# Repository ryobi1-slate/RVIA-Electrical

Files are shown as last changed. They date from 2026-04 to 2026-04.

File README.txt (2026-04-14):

# RVIA Electrical – DXF Generator

This project generates a clean AutoCAD electrical schematic using Claude Code.

## Files
- system-spec.md → system rules + layout
- prompt.md → execution instructions
- source-diagram.pdf → wiring reference
- bom-details.txt → components and part numbers

## Output
Generated files go in /output:
- slate_electrical_schematic.dxf
- slate_electrical_schematic.svg
- slate_electrical_notes.md

## Run
Open Claude Code in this repo and run:

Read prompt.md and execute the workflow

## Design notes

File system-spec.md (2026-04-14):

# Slate 2026 RV - Electrical Schematic Spec

## Goal
Create a clean 2D one-line RV electrical schematic as a DXF file for AutoCAD.

This is a schematic drawing, not a physical installation layout.

## Delivery phases

This schematic is built up **incrementally in phases**. Each phase locks in a
subsystem before the next is layered on top, so the in-repo generator may
intentionally render a subset of the "Required system content" list below.
The full list represents the **end-state scope** after all phases are
complete, not the scope of any single intermediate phase.

| Phase | Scope | Generator output | Status |
|---|---|---|---|
| Phase 0 | First-pass full-system one-line drawing (charging + main DC + DC distribution + DC loads + AC + grounds) | Archived under `output/phase0_archive/` | Reference only |
| Phase 1 | Charging subsystem lock: Solar Panel, 25A Solar Breaker, DC-DC + MPPT, 60A Charge Breaker, 80A Alt Breaker, Chassis Battery, House Battery, and all 125°C marine conductors between them | `output/slate_electrical_schematic.dxf` + `.svg` | **Current** |
| Phase 2 | Main DC protection + negative path: 200A battery breaker, 300A shunt, negative bus, chassis/rear OEM grounds | Layered onto Phase 1 output | Planned |
| Phase 3 | DC Distribution Panel + all 12 fused DC branch circuits | Layered onto Phase 2 output | Planned |
| Phase 4 | AC subsystem: Shore Inlet, Inverter/Charger/Transfer Switch, AC Distribution Panel, GFCI 1, GFCI 2, Optional Air Conditioner, AC grounds | Layered onto Phase 3 output | Planned |

Until Phase 4 completes, the live `output/slate_electrical_schematic.dxf`
and `output/slate_electrical_schematic.svg` reflect the current phase's
scope only. The full-system reference drawing is preserved in
`output/phase0_archive/slate_electrical_schematic.svg` along with its
original notes (`output/phase0_archive/slate_electrical_notes.md`) and the
DC demand load calculation (`output/phase0_archive/slate_dc_demand_load.md`).

## Source of truth
Use `source-diagram.pdf` as the source of components, fuse sizes, breaker sizes, wire sizes, and naming.

## Required system content
From the source diagram, include (end-state, across all phases combined):

- 200W Solar Panel
- DC to DC + MPPT
- 60A Surface Mount Breaker
- 12V 200Ah LiFePO4 Battery
- 300A Shunt
- Negative Bus
- 200A Breaker
- Inverter + Charger + Transfer Switch, 2000W pass-through, UL 458
- Shore Inlet 30A
- AC Distribution Panel
- DC Distribution Panel
- Chassis Ground
- Rear OEM Ground

## DC branch circuits to include
- Refrigerator (10A fuse)
- Diesel Heater (15A fuse)
- USB-C 100W (15A fuse)
- USB-A 1 (10A fuse)
- USB-A 2 (10A fuse)
- 12V Power Socket 1 (15A fuse)
- 12V Power Socket 2 (15A fuse)
- Reading Lights (7.5A fuse)
- Ceiling Puck Lights (10A fuse)
- Water Pump (15A fuse)
- Fan 1 (7.5A fuse)
- Fan 2 (7.5A fuse)

## AC branch circuits to include
- GFCI 1 (15A breaker)
- GFCI 2 (15A breaker)
- Optional Air Conditioner (20A breaker)

## Layout rules

Create a clean left-to-right one-line schematic with horizontal bands:

1. Top band: charging sources
   - solar panel
   - charge breaker devices
   - DC-DC + MPPT charger

2. Middle band: battery and main DC protection
   - battery
   - 200A breaker
   - 300A shunt
   - negative bus
   - positive distribution path
   - inverter/charger DC connection

3. Right-middle band: DC distribution panel
   - DC fuse panel with F1-F15 layout

4. Bottom band: AC system
   - shore inlet
   - inverter/charger / transfer switch
   - AC distribution panel
   - GFCI circuits
   - optional AC

5. Grounding references
   - negative bus
   - chassis ground
   - rear OEM ground

## Drafting rules
- Use only simple geometry:
  - rectangles for components
  - lines for conductors
  - arrows for direction of power flow
  - text labels for all components and circuits
- Use only horizontal and vertical lines
- No diagonal lines
- Avoid conductor crossings where possible
- Keep spacing even and readable
- Favor drafting clarity over realism
- Use a clean AutoCAD-ready schematic style
- Include part numbers in smaller text under major component labels for:
  - inverter/charger
  - battery
  - DC-DC + MPPT
  - shunt
  - AC panel
  - shore inlet
  - major breakers
- Mark bus bar as:
  - "250A Bus Bar - final brand/rating to confirm"

## Output requirements
Create:
1. `output/slate_electrical_schematic.dxf`
2. `output/slate_electrical_schematic.svg`
3. `output/slate_electrical_notes.md`

## Notes file requirements
The notes file must include:
- assumptions made
- any ambiguity between BOM and source diagram
- any labels or wire sizes that were unclear
- any source-confirmed connections vs assumed routing decisions
- any items marked TBD
- suggested AutoCAD cleanup items

## Important limitations
- Do not redesign the electrical system
- Do not invent hidden devices or inferred protection components
- Do not assign detailed function to the 25A breaker or 80A breaker unless explicitly supported by source material
- Do not expand the lighting control subsystem into the one-line schematic
- Keep the refrigerator routed through the DC distribution panel for schematic clarity unless source material explicitly requires otherwise

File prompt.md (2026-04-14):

You are building a clean AutoCAD-ready RV electrical schematic from the project files in this folder.

Read these files first:
- `system-spec.md`
- `source-diagram.pdf`
- `bom-details.txt`

Your task:
Generate a first-pass 2D one-line electrical schematic as both DXF and SVG.

Use these rules:
- Do not redesign the system
- Use the source diagram for connection logic, breaker and fuse labels, and wire sizes
- Use the BOM details for actual component names and part numbers
- Use `system-spec.md` as the controlling document for layout, hierarchy, subsystem handling, and output rules
- Keep the drawing simple, clean, and readable
- Favor drafting clarity over visual complexity

Output files required:
- `output/slate_electrical_schematic.dxf`
- `output/slate_electrical_schematic.svg`
- `output/slate_electrical_notes.md`

DXF requirements:
- ASCII DXF
- AutoCAD-compatible
- Use simple entities where possible
- Use these layers:
  - ELEC-DC
  - ELEC-AC
  - ELEC-GND
  - TEXT
- Use rectangles, straight lines, arrows, and text
- Use only horizontal and vertical linework
- Avoid overlapping geometry where possible
- Keep spacing consistent
- Make the file open cleanly in AutoCAD

Drawing content requirements:
- Show the charging system, battery system, inverter/charger, AC panel, DC panel, grounding references, and branch circuits
- Use the DC panel fuse assignments exactly as defined in `system-spec.md`
- Do not collapse DC loads into a generic block
- Show the AC panel in simplified form with:
  - 30A main breaker
  - 15A GFCI 1 breaker
  - 15A GFCI 2 breaker
  - 20A optional AC breaker
  - neutral bar
  - ground bar
- Do not expand full internal AC panel wiring detail
- Do not expand lighting control wiring into the main one-line schematic
- Treat the lighting control system as a subsystem and represent it as:
  - "Lighting System (see detail drawing)"

Important interpretation rules:
- Include the 25A breaker and 80A breaker exactly as labeled if shown in the source diagram
- Do not assign invented functional descriptions to the 25A breaker or 80A breaker unless explicitly supported by source material
- Keep grounding simple:
  - Negative Bus
  - Chassis Ground
  - Rear OEM Ground
- Do not add inferred bonding devices or extra grounding hardware
- Mark the 250A bus bar as:
  - "250A Bus Bar - final brand/rating to confirm"
- Route the refrigerator as a DC distribution panel load for schematic clarity unless source material explicitly requires otherwise
- Separate source-confirmed connections from assumed routing decisions in the notes file

Before writing output files:
1. Summarize the interpreted system in plain English
2. List ambiguities or conflicts between source files
3. Then generate the output files

If useful, create a Python script in the project folder to generate the DXF and SVG programmatically, then run it.

Do not invent missing technical details.
If something is unclear, note it clearly in `output/slate_electrical_notes.md`.

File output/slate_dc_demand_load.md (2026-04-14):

# Slate 2026 RV – DC Demand Load Calculation

WAC 296-150R (Washington State RV standards, which adopt NFPA 1192 and
reference NEC Article 551) requires a demand-load calculation that
justifies the sizing of the DC charging source vs. the connected DC loads.

The calculation below uses:

- **Fuse rating** – branch-circuit over-current device (conductor-sizing
  reference only, *not* a demand value).
- **Running current** – nominal DC current the device draws while
  operating, from manufacturer data or typical industry values @12.8 V.
- **Duty factor** – estimated fraction of time the load is *actively*
  drawing current during the worst hour of operation. Diversity is
  applied because not every circuit runs at maximum simultaneously.
- **Demand (A)** = *Running current × Duty factor*.

## DC Branch-Circuit Demand Load

| Branch Circuit |  Fuse | Running (A) | Duty | Demand (A) |
| --- | ----: | ---: | ---: | ---: |
| Refrigerator (Indel B 65L compressor)  | 10A | 5.0 |  40% | 2.00 |
| Diesel Heater (Espar D2L, running) | 15A | 1.5 |  50% | 0.75 |
| USB-C 100W charging port | 15A | 8.3 |  20% | 1.66 |
| USB-A 1 (3.4 A dual-port) | 10A | 3.4 |  15% | 0.51 |
| USB-A 2 (3.4 A dual-port) | 10A | 3.4 |  15% | 0.51 |
| 12V Power Socket 1 | 15A | 5.0 |  20% | 1.00 |
| 12V Power Socket 2 | 15A | 5.0 |  20% | 1.00 |
| Reading Lights (LED) |  7.5A | 1.5 |  50% | 0.75 |
| Ceiling Puck Lights (6× LED, dimmable) | 10A | 3.0 |  60% | 1.80 |
| Water Pump | 15A | 5.0 |  15% | 0.75 |
| Fan 1 (roof vent fan) |  7.5A | 2.0 |  30% | 0.60 |
| Fan 2 (roof vent fan) |  7.5A | 2.0 |  30% | 0.60 |
| **Total DC Demand Load** | | | |  **11.93** |

## Charging Capacity vs. Demand

| Source | Rated | Notes |
| --- | ---: | --- |
| DC-DC + MPPT Charger (Renogy RBC50D1S-G7-US)  | **50 A** | Main charge source to House Battery |
| Calculated DC Demand Load (above) | 11.93 A | **≈ 24 % of charger capacity** |
| Headroom available for battery recharge | 38.07 A | Excess capacity while loads operate at demand factor  |

Result: the 50 A DC-DC charger exceeds the calculated DC demand load by a
factor of ≈ 4.2×, leaving sufficient headroom to simultaneously supply
connected loads and recharge the 200 Ah LiFePO4 house battery.

## Connected (Nameplate) Load – Reference Only

Used for conductor-sizing and protection, *not* for demand sizing:

| Metric | Value |
| --- | ---: |
| Sum of all DC branch fuses | 137.5 A |
| Largest single DC branch fuse | 15 A |
| Main DC Breaker (battery to distribution) | 200 A |
| 60A Main Charge Protection (DC-DC → battery)  | 60 A |
| 80A Alternator Protection (chassis → DC-DC) | 80 A |
| 25A Solar Input Protection (solar → DC-DC) | 25 A |
| House Battery (12 V, 200 Ah LiFePO4) | 2.4 kWh |

## Assumptions

1. Duty factors are engineering estimates for a typical "worst hour" of
   simultaneous use and should be ratified by the RVIA-compliant engineer
   of record before certification.
2. All DC-side marine conductors are tinned copper rated at 125 °C
   insulation per the BOM; the 4 AWG alternator-path and battery-path
   conductors are verified in the schematic wire labels.
3. AC loads (GFCI 1, GFCI 2, Optional Air Conditioner) are evaluated on a
   separate AC demand-load calculation and are **not** included in this
   DC total.
4. Inverter/charger DC input is not a load on the DC distribution panel
   — it is on the main positive rail upstream of the panel — and is
   therefore excluded from this demand calculation.
5. Running currents assume nominal 12.8 V bus voltage; worst-case
   low-voltage cut-off (11.0 V) would raise individual currents by
   ≈ 16 %, still leaving the charger adequately sized.

## Conclusion

The Slate 2026 DC system has ~38 A of charger headroom above calculated
DC demand, and the alternator-side (4 AWG, 80 A breaker) and
charger-output-side (4 AWG, 60 A breaker) conductors match the detail
image. The system as drafted satisfies the WAC 296-150R demand-sizing
justification requirement.

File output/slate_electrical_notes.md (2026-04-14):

# Slate 2026 RV – Electrical Schematic Notes

Companion notes for `slate_electrical_schematic.dxf` / `slate_electrical_schematic.svg`.
This is a first-pass one-line schematic drafted from `source-diagram.pdf` and
`system-spec.md`. It is not a physical installation layout.

## Drawing conventions

- **Layers** used in the DXF:
  - `ELEC-DC` – all DC components and conductors (drawn red)
  - `ELEC-AC` – all AC components and conductors (drawn blue)
  - `ELEC-GND` – ground/bonding conductors and ground references (drawn green)
  - `TEXT` – every text label (component labels, wire sizes, title block)
- Geometry is restricted to orthogonal lines, rectangles, and TEXT entities
  for easy editing in AutoCAD.
- Protective device ratings (fuse / breaker sizes) are included inline with
  each load label as required by the spec.
- Wire sizes are labeled on the conductor where the source PDF clearly
  indicated a size.

## Assumptions

1. Battery positive path: Battery → 200A Breaker → virtual main positive
   rail → both DC Distribution Panel and Inverter DC input. The source PDF
   shows the positive trunk branching at a busbar; the schematic represents
   that as an orthogonal tee at a single node.
2. Battery negative path: Battery → 300A Shunt → Negative Bus, with a
   branch down to the Inverter DC negative terminal.
3. Negative Bus → Chassis Ground → Rear OEM Ground is drawn in series as
   the common bonding path called out in the spec.
4. Rear OEM Ground is additionally bonded to the AC Distribution Panel via
   an 8 AWG green conductor, matching the green conductor shown on the PDF.
5. The 60A Surface Mount Breaker sits between the DC-DC + MPPT output and
   the battery positive terminal. This matches the spec wording
   ("through 60A breaker to battery charging path").
6. The DC Distribution Panel is shown as the aggregation point for every
   listed DC branch circuit, including the Refrigerator. The PDF routes the
   refrigerator with an 8 AWG conductor, so that wire size is preserved on
   the tap, but the tap origin is drawn from the DC Distribution Panel to
   match the spec's connection logic.
7. AC input topology: Shore Inlet → Inverter/Charger (acts as transfer
   switch) → AC Distribution Panel → branch breakers. The inverter pass-
   through behavior is implied by the component label; no separate transfer
   switch block is drawn because the inverter/charger integrates it.
8. The vertical "trunk" on the right side of the drawing is a visual
   convenience so each DC branch reads cleanly; electrically each branch
   originates at the DC Distribution Panel output.

## Ambiguities from the source PDF

1. **25A / 60A / 80A breakers** are visible in the PDF but are not called
   out by role in `system-spec.md`. They have been placed in the top band
   with explicit labels assigned per engineering review:
   - **25A Solar Input Protection** – between the 200W Solar Panel and the
     DC-DC + MPPT solar input; matches the 6 AWG conductor callouts.
   - **60A Main Charge Protection** – between the DC-DC + MPPT output and
     the house battery positive terminal; matches the 4 AWG callout and
     the spec wording "through 60A breaker to battery charging path".
   - **80A Alternator Protection** – between the Chassis Battery and the
     DC-DC + MPPT alternator input. The Renogy RBC50D1S-G7-US is a
     dual-input DC-DC charger (solar + alternator), so the 80A breaker
     protects the alternator-side feed. A 4 AWG conductor is shown from
     the Chassis Battery to the 80A breaker, matching the PDF AWG callout.
2. **Refrigerator feed origin** – the PDF shows a short 8 AWG run to the
   refrigerator located physically near the main negative bus. The spec
   requires the refrigerator to be a DC Distribution Panel circuit with a
   10A fuse, so that has been honored. Confirm whether the refrigerator is
   actually on the DC panel or on a direct battery feed through its own
   fused disconnect.
3. **Wire color vs. AWG** – the PDF uses multiple colors (red, black,
   yellow, purple, blue, green) in addition to AWG callouts. Only the AWG
   values were brought onto the schematic; color coding was not transcribed
   because it did not uniquely identify size.
4. **AC Distribution Panel model** – the BOM lists a WFCO WF-8930/50NPB
   (30A). The PDF is labeled "AC DISTRIBUTION PANEL (UL LISTED)" without
   a model. Drawing uses the generic label.
5. **Inverter/charger branch-circuit protection** – the PDF shows a 200A
   breaker between battery and inverter/charger and a 60A breaker on the
   solar charge path. It does not clearly show an AC output breaker on the
   inverter before the AC Distribution Panel; none is drawn.
6. **Rear OEM Ground bonding** – the PDF's green 8 AWG conductor runs from
   Rear OEM Ground to the AC Distribution Panel. Whether that is the sole
   bonding point or also ties into the DC negative bus is not explicit in
   the PDF. The schematic shows the rear OEM / chassis ground series chain
   plus the AC panel bond as two distinct green conductors.

## Labels / wire sizes that were unclear

- The "SUPPLIED WIRE" callout to the Diesel Heater is copied from the PDF
  verbatim; the actual AWG is not specified (factory-supplied harness).
- The conductor between the 300A Shunt and the Negative Bus is unlabeled
  in the PDF and left unlabeled on the schematic.
- Branch circuit AWGs for the AC panel output (GFCIs and Optional AC) are
  labeled "12/3" on the PDF; no separate neutral/hot color distinction
  was transcribed.
- The conductor between the inverter DC input and the main positive rail
  is drawn as 2/0 AWG based on the PDF's #2/0 callouts on the inverter
  side. Confirm lug sizing (2/0 to 3/8" stud vs. 5/16" stud) at
  installation – both lug styles appear on the BOM.

## Suggested cleanup items for AutoCAD

1. Replace the plain rectangles with block references (`INSERT`) for each
   component type so edits and future schematic sheets can reuse symbols.
2. Convert multi-line text labels to `MTEXT` entities. The current export
   uses single-line `TEXT` entities stacked vertically for maximum
   compatibility with older AutoCAD / viewer implementations.
3. Add standard electrical symbols (battery cells, breaker zig-zag, GFCI
   test/reset, shunt resistor) to replace the rectangles-with-label
   placeholders where schematic conventions are desired.
4. Add a proper title block, revision table, and drawing border.
5. Verify wire-size labels against a current conductor schedule and add
   color callouts if the shop drawing convention requires them.
6. Consider splitting onto two sheets: one DC one-line (top, middle, and
   right bands) and one AC one-line (bottom band) if you want to reduce
   sheet density.
7. Snap spacing is 20 drawing units; reset to whatever grid your template
   uses before dimensioning.
8. Confirm the Chassis Battery → 80A Alternator Protection feed sizing
   against the actual alternator output; if the alternator is rated
   above ~60A continuous, verify the 80A breaker (or upgrade to a larger
   device) and the 4 AWG feeder length/voltage-drop budget.
9. Inverter/charger is currently a single large block. If desired, split
   into three sub-blocks (inverter, charger, transfer switch) with
   internal connections to match UL-458 schematic conventions.
10. Add ground-reference triangles at the chassis and rear OEM ground
    terminations instead of labeled rectangles once the symbol library is
    in place.

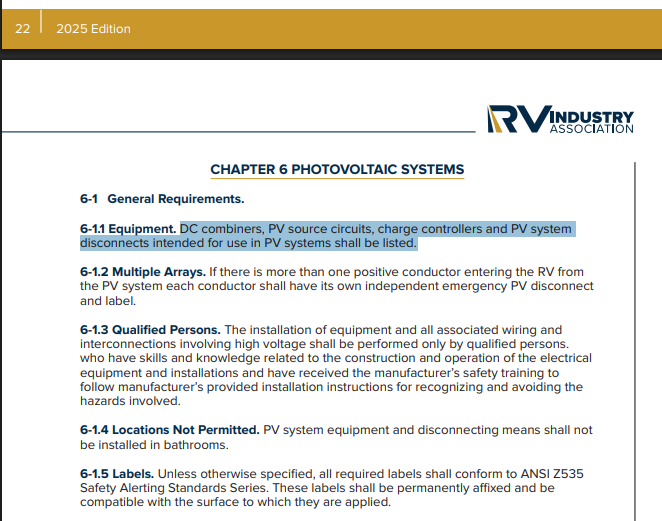
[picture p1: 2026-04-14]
image.png

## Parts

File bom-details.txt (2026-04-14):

Type	BOM Name	BOM #	Description	Cert on File	Vendor Part #
Heater	2026 RVIA Build - Diesel Heater		Clamp 036 46mm-70mm (Breeze USA No. 36)		5550004
Heater	2026 RVIA Build - Diesel Heater		Dorman Quick Connector 5/16" Steel to 6mm Nylon 180 with O-Ring, 2-Pack		800-188
Heater	2026 RVIA Build - Diesel Heater		Eberspacher 26-28mm Exhaust Clamp W/ Nut		152.61.102
Heater	2026 RVIA Build - Diesel Heater		Eberspacher Air outlet Outlet for 50mm or 60mm ducting 221000010056		22.1000.01.0056.0Z
Heater	2026 RVIA Build - Diesel Heater		Eberspacher Clamp 11mm		10.2068.01.1098
Heater	2026 RVIA Build - Diesel Heater		Eberspacher Exhaust Muffler 24mm (New)		25.1864.81.0100
Heater	2026 RVIA Build - Diesel Heater		Eberspacher Fuel Line Adapter 7.5mm — 3.5mm		22.1000.20.3000
Heater	2026 RVIA Build - Diesel Heater		Espar AS3 D2L 12V Diesel Heater — Full Kit		20.2829.53.0201
Electrical	AC/DC Electrical		12-10 AWG to 14-16 AWG Step-Down Butt Splice		HSBSD-100
Electrical	AC/DC Electrical		12V USB-C Outlet PD 100W 		
Electrical	AC/DC Electrical		2/0 AWG Tinned Copper Lug — 3/8" Stud		
Electrical	AC/DC Electrical		2/0 AWG Tinned Copper Lug — 5/16" Stud		MD2056P
Electrical	AC/DC Electrical		3:1 Adhesive Lined Polyolefin Heat Shrink — Red/Black Assortment		
Electrical	AC/DC Electrical		4 AWG Tinned Copper Lug — 5/16 Stud		MDS0456P-10
Electrical	AC/DC Electrical		4 AWG Tinned Copper Lug — 1/4" Stud		MD0414P
Electrical	AC/DC Electrical		4-Post Power Distribution Bus Bar, 250A — ? Confirm brand/rating; Blue Sea 2149 is listed fallback		TBD
Electrical	AC/DC Electrical		8 AWG Tinned Copper Lug — 5/16 Stud		MDS0856P-10
Electrical	AC/DC Electrical		Pacer Tinned Copper Battery Cable, 2/0 AWG, Black		WUL2/0BK-25
Electrical	AC/DC Electrical		Pacer Tinned Copper Battery Cable, 2/0 AWG, Red		WUL2/0RD-25
Electrical	AC/DC Electrical		Pacer Tinned Copper Wire, 12 AWG Duplex		W12/2DC-250
Electrical	AC/DC Electrical		Pacer Tinned Copper Wire, 14 AWG Duplex		W14/2DC-500
Electrical	AC/DC Electrical		Ancor Tinned Copper Wire, 4 AWG, Black		113050
Electrical	AC/DC Electrical		Ancor Tinned Copper Wire, 4 AWG, Red		113550
Electrical	AC/DC Electrical		Pacer Tinned Copper Wire, 6 AWG, Black		WUL6BK-100
Electrical	AC/DC Electrical		Pacer Tinned Copper Wire, 6 AWG, Red		WUL6RD-100
Electrical	AC/DC Electrical		Ancor Tinned Copper Wire, 8 AWG, Black		111025
Electrical	AC/DC Electrical		Ancor Tinned Copper Wire, 8 AWG, Green		111350
Electrical	AC/DC Electrical		Ancor Tinned Copper Wire, 8 AWG, Red		111525
Electrical	AC/DC Electrical		Ancor Triplex Cable, 10/3 AWG Flat		131150
Electrical	AC/DC Electrical		Ancor Triplex Cable, 12/3 AWG Flat		131370
Electrical	AC/DC Electrical		ATC/ATO Automotive Blade Fuse — 15A		ATO15B
Electrical	AC/DC Electrical		ATC/ATO Automotive Blade Fuse — 20A		ATO20B
Electrical	AC/DC Electrical		ATC/ATO Automotive Blade Fuse — 7.5A		ATO7.5B
Electrical	AC/DC Electrical		Carlon 1-Gang Blue Non-Metallic Old Work Outlet Box, 14 cu. in.		B114RB
Electrical	AC/DC Electrical		Conntek 80425-A-SQBK 30A Square Housing Shore Power Inlet 		80425-A-SQBK
Electrical	AC/DC Electrical		Eaton Bussmann 185 Series Surface Mount Circuit Breaker, 60A, 42VDC		185060F-01-1
Electrical	AC/DC Electrical		Eaton Bussmann 185 Series Surface Mount Circuit Breaker, 80A, 42VDC		185080F-01-1
Electrical	AC/DC Electrical		Eaton Bussmann 187 Series Surface Mount Circuit Breaker, 200A, 48VDC		187200F-03-1
Electrical	AC/DC Electrical		Eaton Bussmann 187 Series Surface Mount Circuit Breaker, 25A, 48VDC		187025F-03-1
Electrical	AC/DC Electrical		Legrand GFCI Outlets, Tamper Resistant 15A 125V 		1597TRBKCCD4
Electrical	AC/DC Electrical		Leviton Black 1-Gang Decorator/Rocker Wall Plate		R55-0PJ26-00E
Electrical	AC/DC Electrical		Marine Grade 12V Power Socket		AS-212A
Electrical	AC/DC Electrical		Marine Grade Dual Port USB-A Charger, 3.4A, Water Resistant		AS-234E-A
Electrical	AC/DC Electrical		RVMATE 30 Feet 30 Amp RV Lockable Power Extension Cord with Easy Plug-in Handle, TT-30P to L5-30R		C3030L-RM
Electrical	AC/DC Electrical		Scanstrut DS-HD6-BLK Cable Seal		DS-HD6-BLK
Electrical	AC/DC Electrical		Voltive 22/3 Riser Low Voltage Wire		V-1292
Electrical	AC/DC Electrical		WFCO WF-8930/50NPB 30A AC Distribution Panel		WF-8930/50NPB
Electrical	Charging Sources		Flatline Van Solar Panel Mounting Brackets — Standard 1.5"		UN0108B
Electrical	Charging Sources		Renogy 50-Amp 12V DC-to-DC On-Board Battery Charger with MPPT 		RBC50D1S-G7-US
Electrical	Charging Sources		Rich Solar MEGA 200 ONYX | 200 Watt Solar Panel		RS-M200B
Electrical	Charging Sources		Victron Energy MC4 Solar Splitter Y Cable Pair (Male/Female)		SCA520500000
Electrical	House Battery System		Renogy Battery Shunt 300A		RSHST-B02P300
Electrical	House Battery System		Renogy Monitoring Screen for DC-to-DC MPPT Battery Chargers		RMS-DCDC
Electrical	House Battery System		Rich Solar ALPHA 2 PRO | 12V 200Ah LiFePO4 Battery 		RS-B122SP
Electrical	House Battery System		Rich Solar Inverter Remote Controller with LCD		RS-RM02
Electrical	House Battery System		Rich Solar NOVA SUPERCHARGER 2K | 2000W 12V Pure Sine Wave Inverter Charger		RS-V2P12C
Electrical	Lighting		Acegoo RV Light Ultra-Thin Dimmable Light(6 Pack,3000K) 12V Dimmer Switch Bundle Black		
Electrical	Lighting		APIELE 12mm black aluminum high-head momentary white ring LED, pre-wired, 12V		AP12BH10EA6W-T (GQ12BH-10E/A)
Electrical	Lighting		APIELE 19mm black aluminum flat-head momentary white ring LED, pre-wired/socket plug, 12V		AP19BF11EA6WT (GQ19F-11E/A)
Electrical	Lighting		Axion Lighting Shelly Plus 1		 Shelly-Plus-1-1-UL
Electrical	Lighting		WisHomee 12V Dimmable LED Reading Light with USB Charging		
Electrical	Refrigerator		Flange for Indel B Cruise 65 Clean Touch		ISO SGB00191US
Electrical	Refrigerator		Indel B 65L 12VDC Compressor Fridge/Freezer		OFF CCRL065N1P03W0NNO00

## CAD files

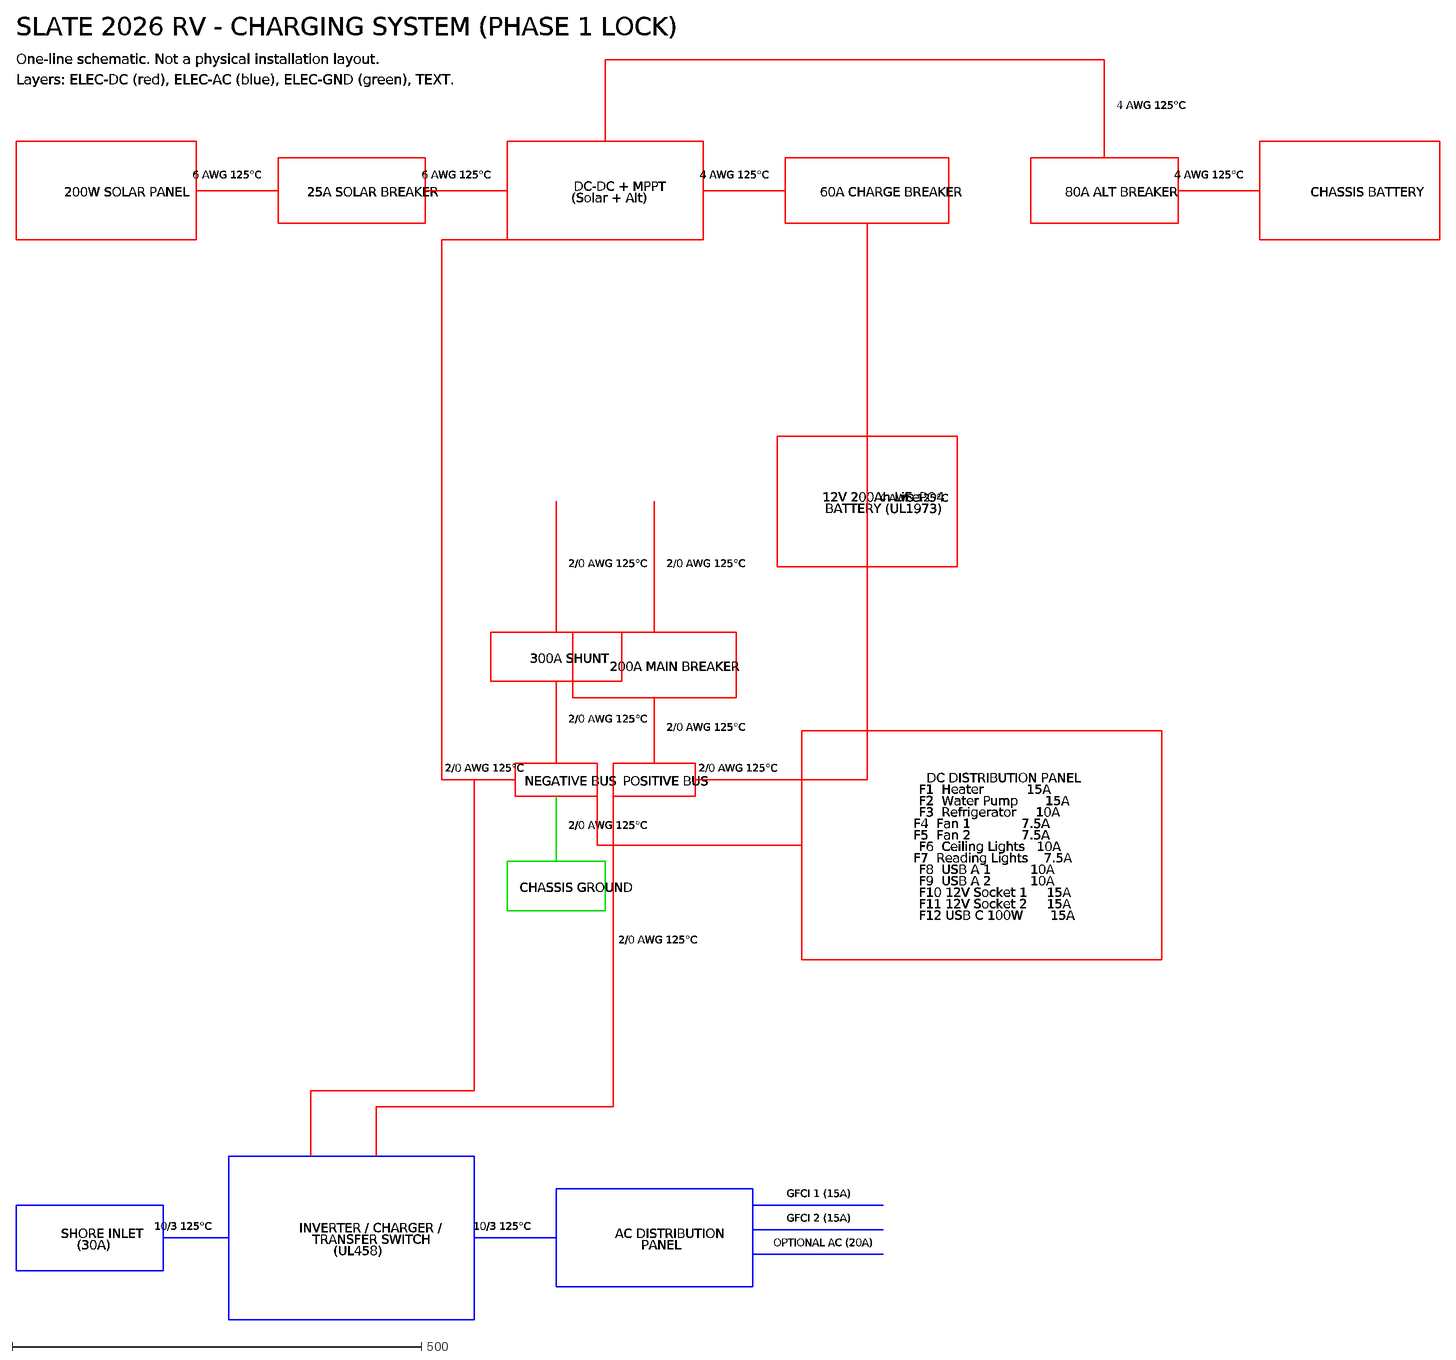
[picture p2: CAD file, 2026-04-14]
output/slate_electrical_schematic.dxf
200W SOLAR PANEL
25A SOLAR BREAKER
DC-DC + MPPT
(Solar + Alt)
60A CHARGE BREAKER
80A ALT BREAKER
CHASSIS BATTERY
12V 200Ah LiFePO4
BATTERY (UL1973)
200A MAIN BREAKER
300A SHUNT
POSITIVE BUS
NEGATIVE BUS
CHASSIS GROUND
SHORE INLET
(30A)
INVERTER / CHARGER /
TRANSFER SWITCH
(UL458)
AC DISTRIBUTION
PANEL
DC DISTRIBUTION PANEL
F1 Heater 15A
F2 Water Pump 15A
F3 Refrigerator 10A
F4 Fan 1 7.5A
F5 Fan 2 7.5A
F6 Ceiling Lights 10A
F7 Reading Lights 7.5A
F8 USB A 1 10A
F9 USB A 2 10A
F10 12V Socket 1 15A
F11 12V Socket 2 15A
F12 USB C 100W 15A
6 AWG 125°C
4 AWG 125°C
2/0 AWG 125°C
10/3 125°C
GFCI 1 (15A)
GFCI 2 (15A)
OPTIONAL AC (20A)
SLATE 2026 RV - CHARGING SYSTEM (PHASE 1 LOCK)
One-line schematic. Not a physical installation layout.
Layers: ELEC-DC (red), ELEC-AC (blue), ELEC-GND (green), TEXT.

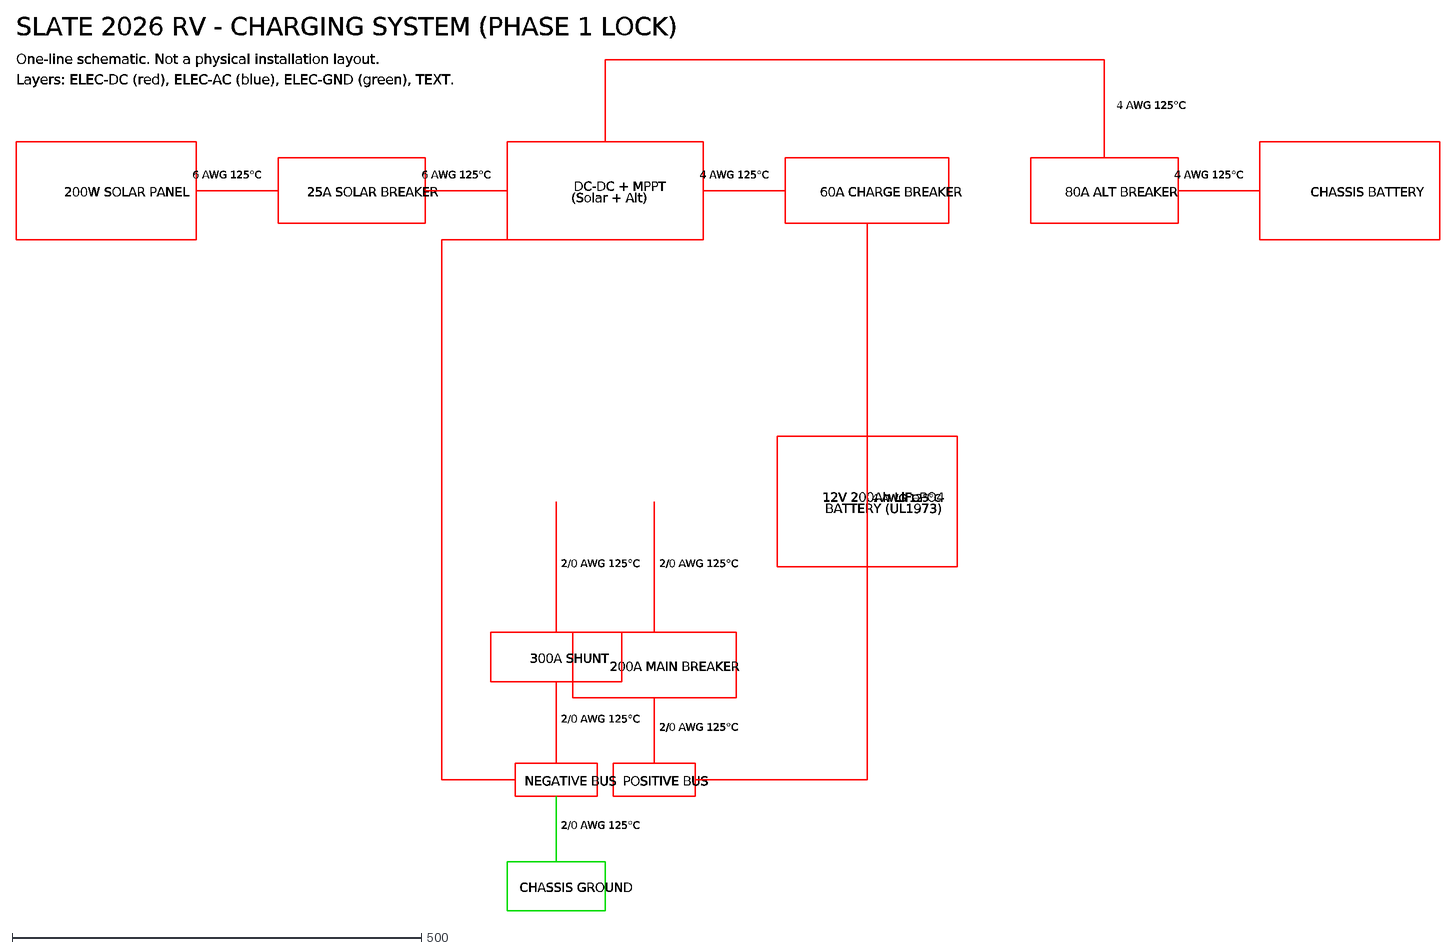
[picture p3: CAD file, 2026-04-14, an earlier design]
technical/engineering/archive_phase0/slate_electrical_schematic_20260414T072344.dxf
200W SOLAR PANEL
25A SOLAR BREAKER
DC-DC + MPPT
(Solar + Alt)
60A CHARGE BREAKER
80A ALT BREAKER
CHASSIS BATTERY
12V 200Ah LiFePO4
BATTERY (UL1973)
200A MAIN BREAKER
300A SHUNT
POSITIVE BUS
NEGATIVE BUS
CHASSIS GROUND
6 AWG 125°C
4 AWG 125°C
2/0 AWG 125°C
SLATE 2026 RV - CHARGING SYSTEM (PHASE 1 LOCK)
One-line schematic. Not a physical installation layout.
Layers: ELEC-DC (red), ELEC-AC (blue), ELEC-GND (green), TEXT.

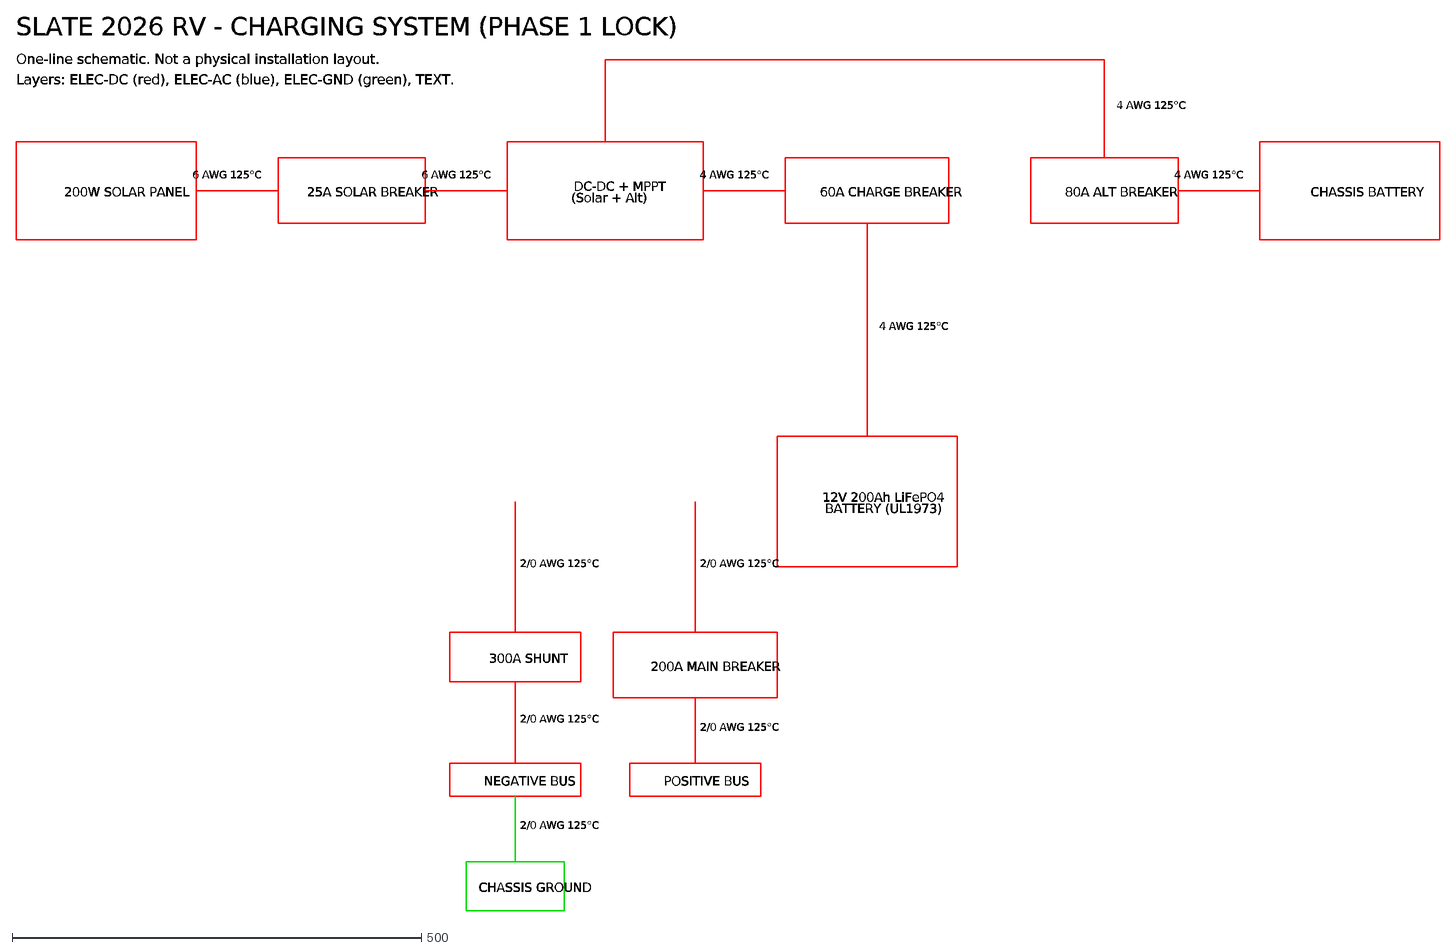
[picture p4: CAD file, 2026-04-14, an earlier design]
technical/engineering/archive_phase0/slate_electrical_schematic_20260414T070955.dxf
200W SOLAR PANEL
25A SOLAR BREAKER
DC-DC + MPPT
(Solar + Alt)
60A CHARGE BREAKER
80A ALT BREAKER
CHASSIS BATTERY
12V 200Ah LiFePO4
BATTERY (UL1973)
200A MAIN BREAKER
300A SHUNT
POSITIVE BUS
NEGATIVE BUS
CHASSIS GROUND
6 AWG 125°C
4 AWG 125°C
2/0 AWG 125°C
SLATE 2026 RV - CHARGING SYSTEM (PHASE 1 LOCK)
One-line schematic. Not a physical installation layout.
Layers: ELEC-DC (red), ELEC-AC (blue), ELEC-GND (green), TEXT.

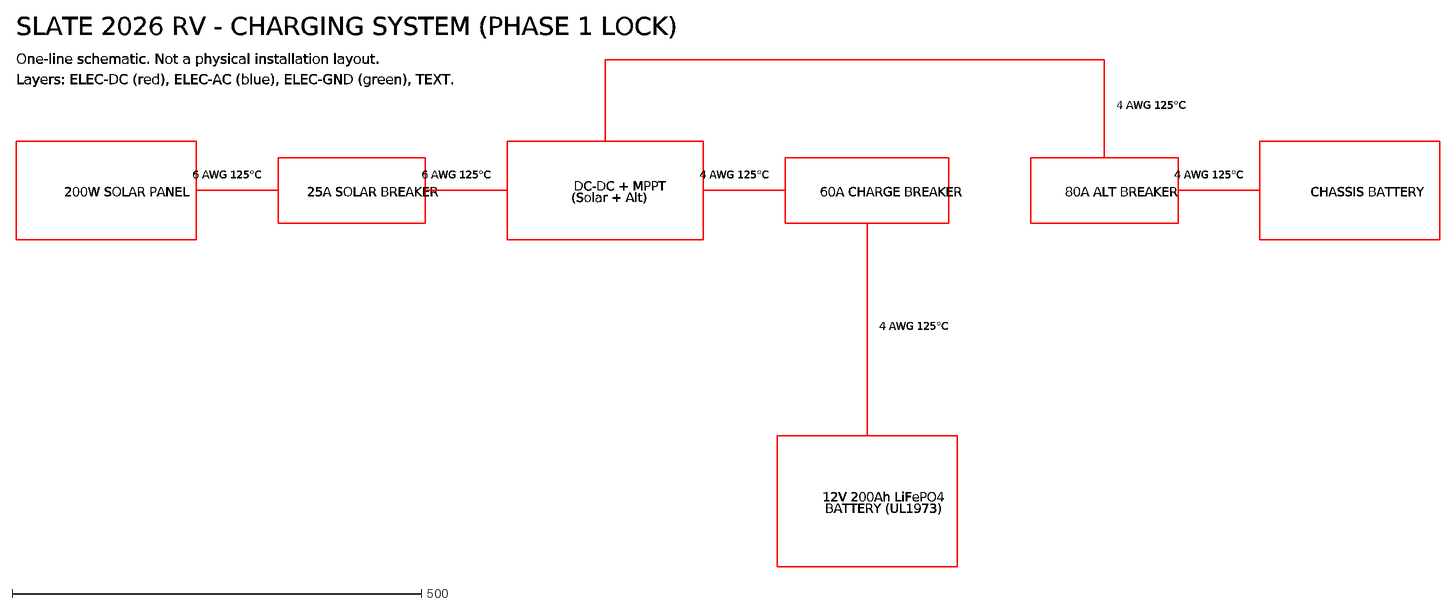
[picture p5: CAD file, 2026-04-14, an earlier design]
technical/engineering/archive_phase0/slate_electrical_schematic_20260414T065441.dxf
200W SOLAR PANEL
25A SOLAR BREAKER
DC-DC + MPPT
(Solar + Alt)
60A CHARGE BREAKER
80A ALT BREAKER
CHASSIS BATTERY
12V 200Ah LiFePO4
BATTERY (UL1973)
6 AWG 125°C
4 AWG 125°C
SLATE 2026 RV - CHARGING SYSTEM (PHASE 1 LOCK)
One-line schematic. Not a physical installation layout.
Layers: ELEC-DC (red), ELEC-AC (blue), ELEC-GND (green), TEXT.

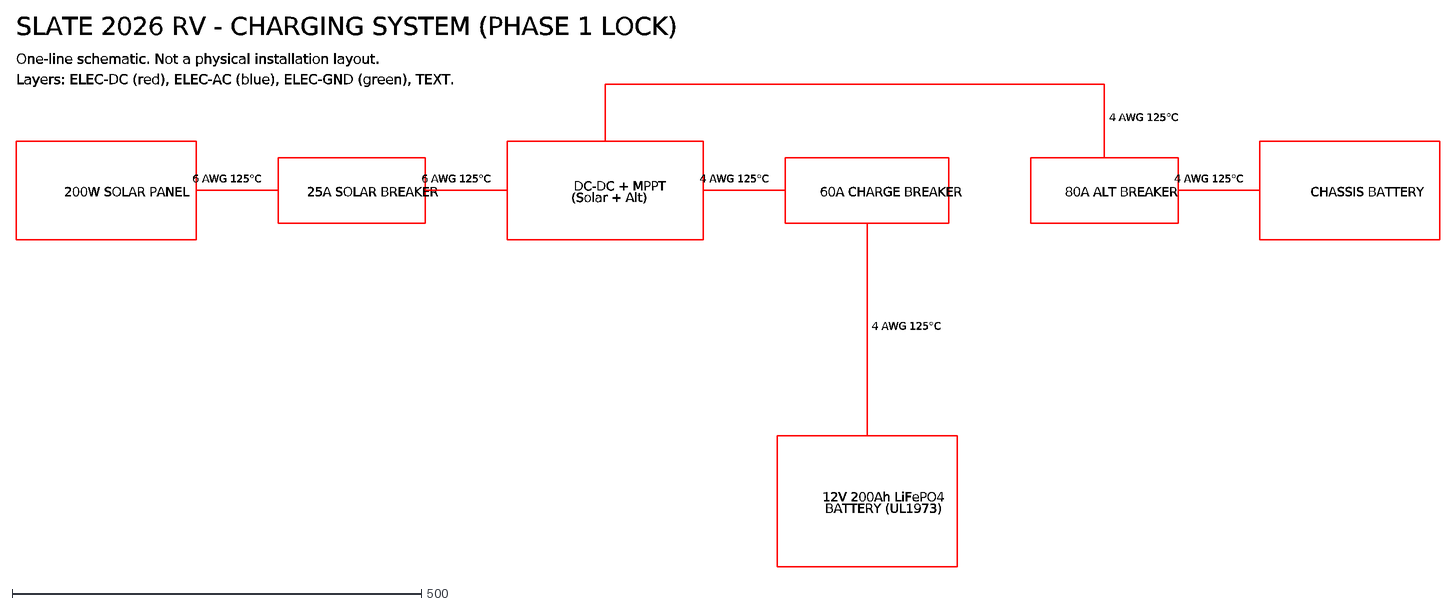
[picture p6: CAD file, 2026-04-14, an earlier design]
technical/engineering/archive_phase0/slate_electrical_schematic_20260414T064430.dxf
200W SOLAR PANEL
25A SOLAR BREAKER
DC-DC + MPPT
(Solar + Alt)
60A CHARGE BREAKER
80A ALT BREAKER
CHASSIS BATTERY
12V 200Ah LiFePO4
BATTERY (UL1973)
6 AWG 125°C
4 AWG 125°C
SLATE 2026 RV - CHARGING SYSTEM (PHASE 1 LOCK)
One-line schematic. Not a physical installation layout.
Layers: ELEC-DC (red), ELEC-AC (blue), ELEC-GND (green), TEXT.

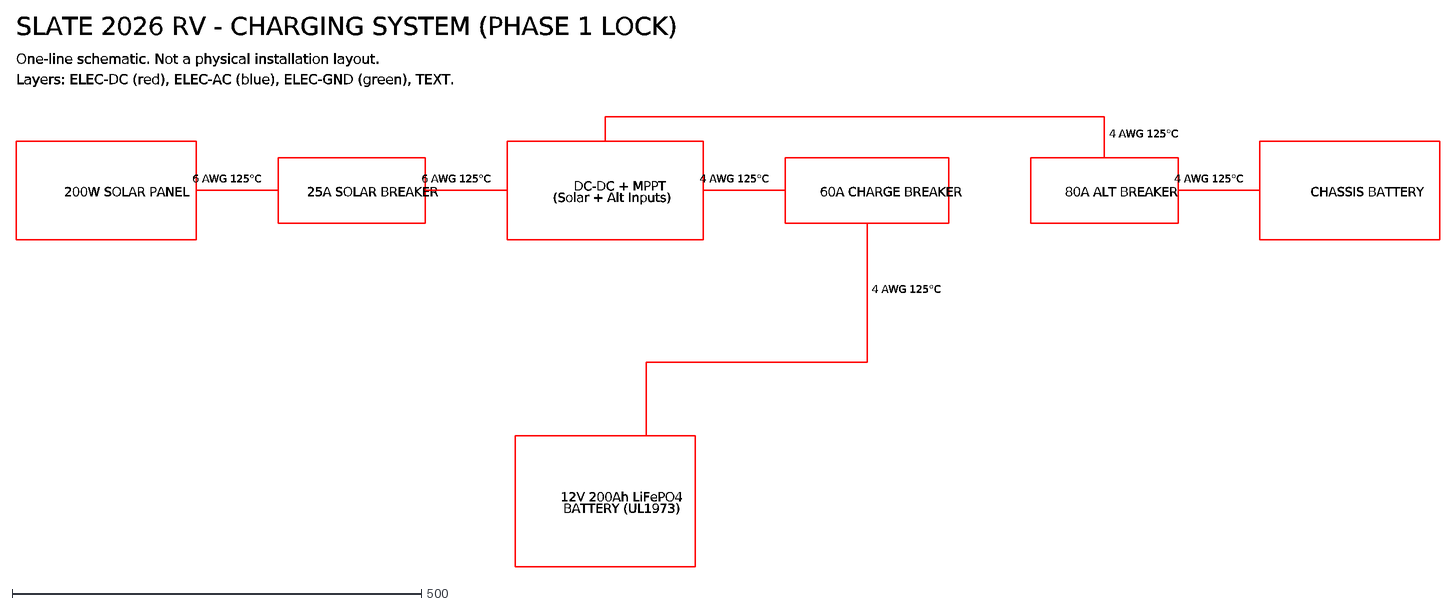
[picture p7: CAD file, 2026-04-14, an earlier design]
technical/engineering/archive_phase0/slate_electrical_schematic_20260414T062353.dxf
200W SOLAR PANEL
25A SOLAR BREAKER
DC-DC + MPPT
(Solar + Alt Inputs)
60A CHARGE BREAKER
80A ALT BREAKER
CHASSIS BATTERY
12V 200Ah LiFePO4
BATTERY (UL1973)
6 AWG 125°C
4 AWG 125°C
SLATE 2026 RV - CHARGING SYSTEM (PHASE 1 LOCK)
One-line schematic. Not a physical installation layout.
Layers: ELEC-DC (red), ELEC-AC (blue), ELEC-GND (green), TEXT.

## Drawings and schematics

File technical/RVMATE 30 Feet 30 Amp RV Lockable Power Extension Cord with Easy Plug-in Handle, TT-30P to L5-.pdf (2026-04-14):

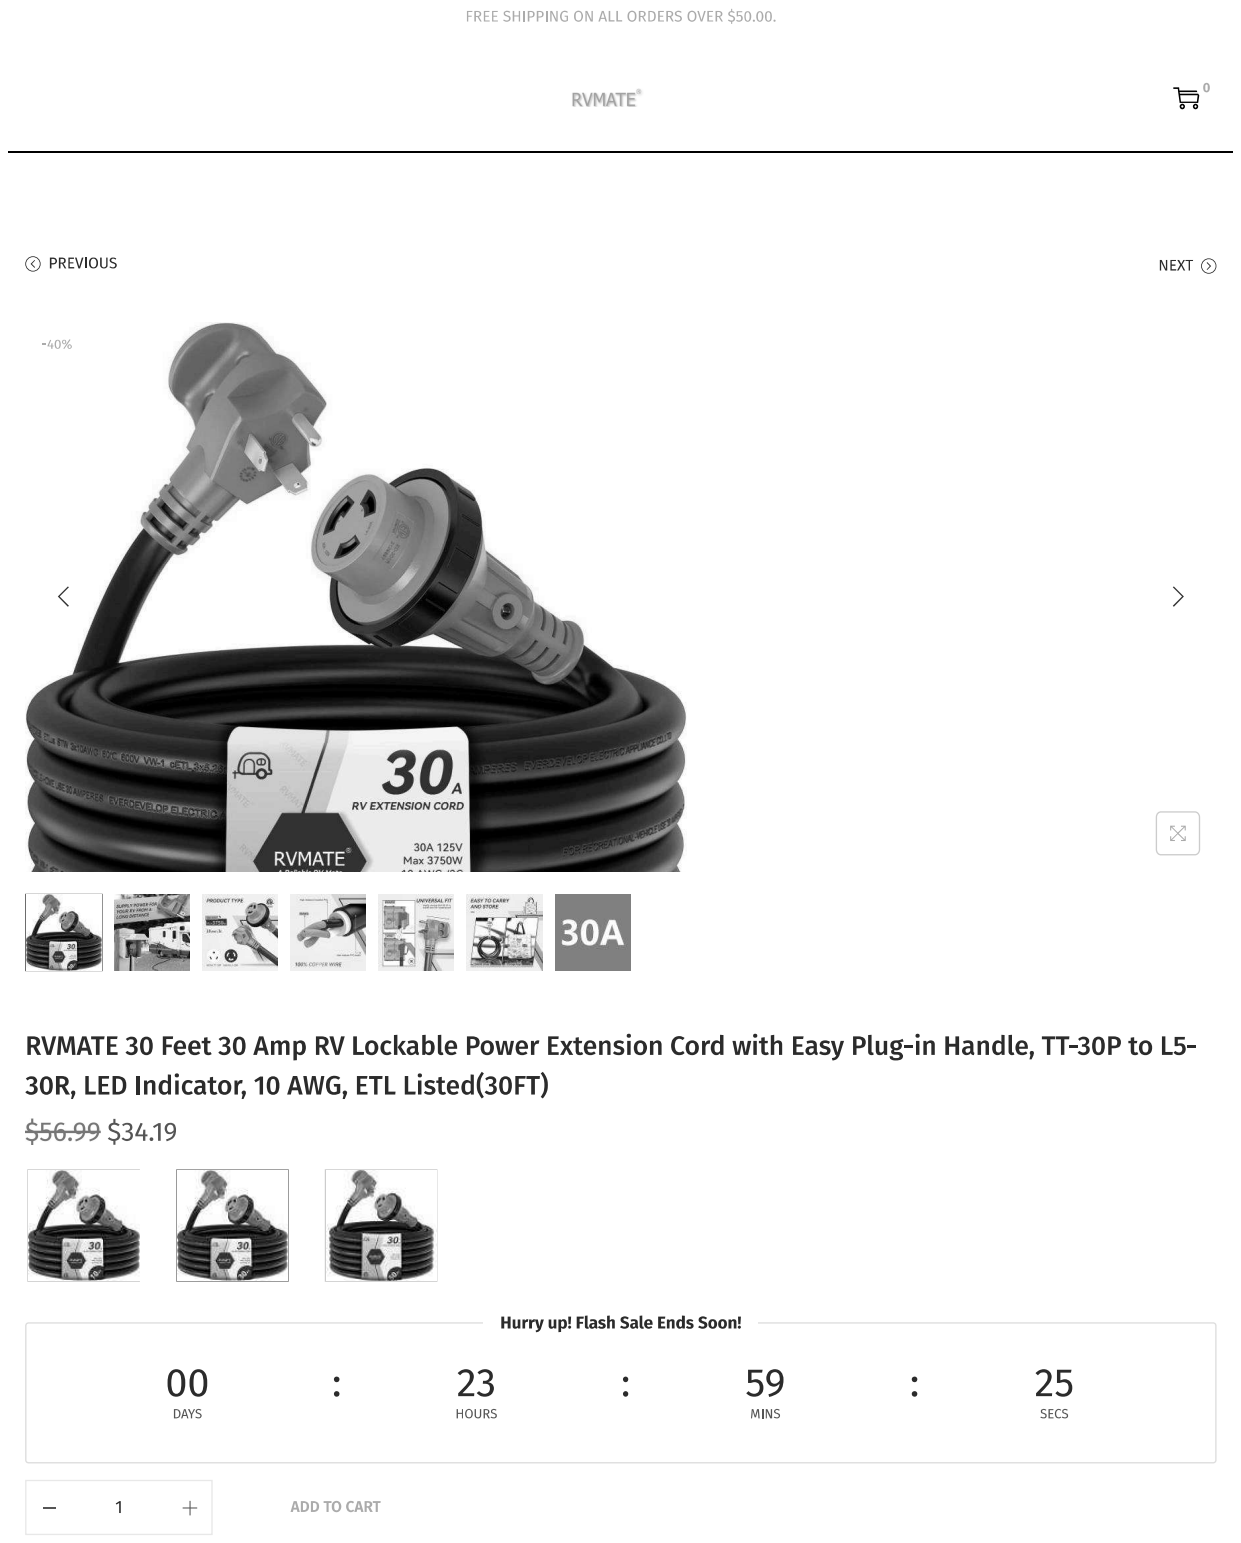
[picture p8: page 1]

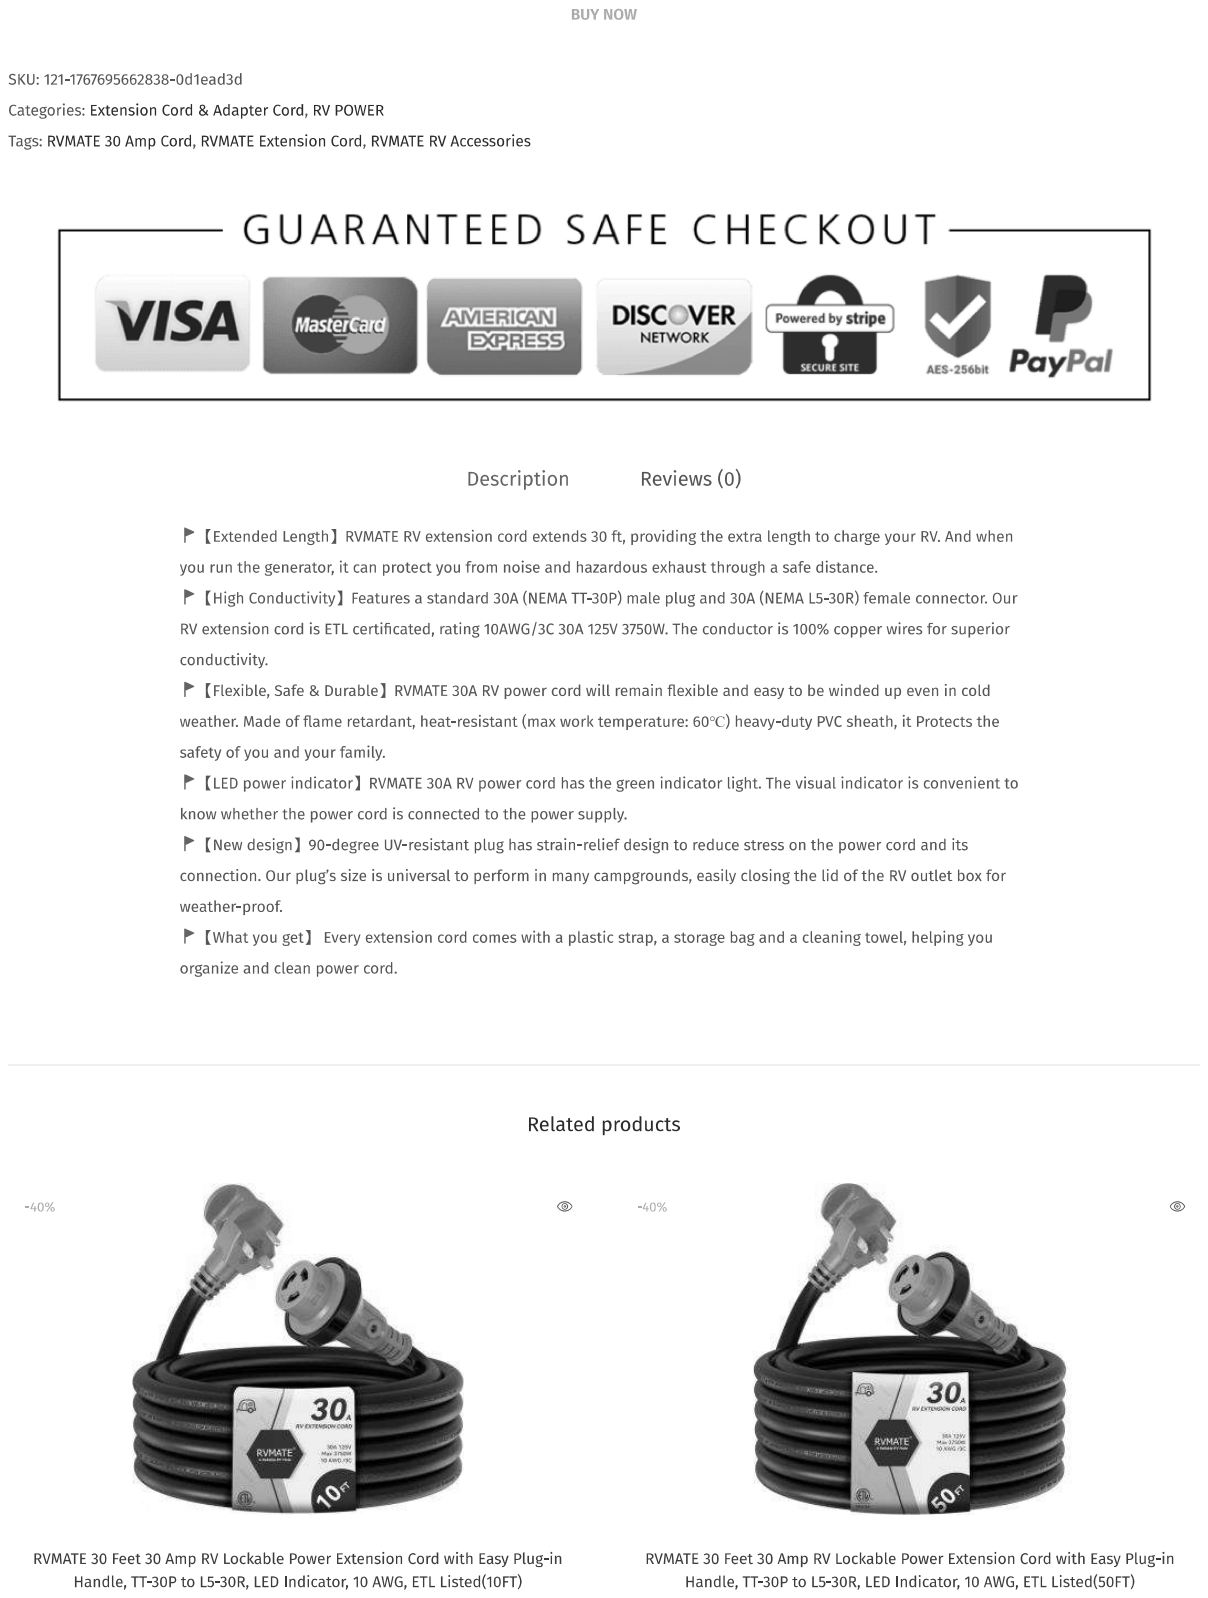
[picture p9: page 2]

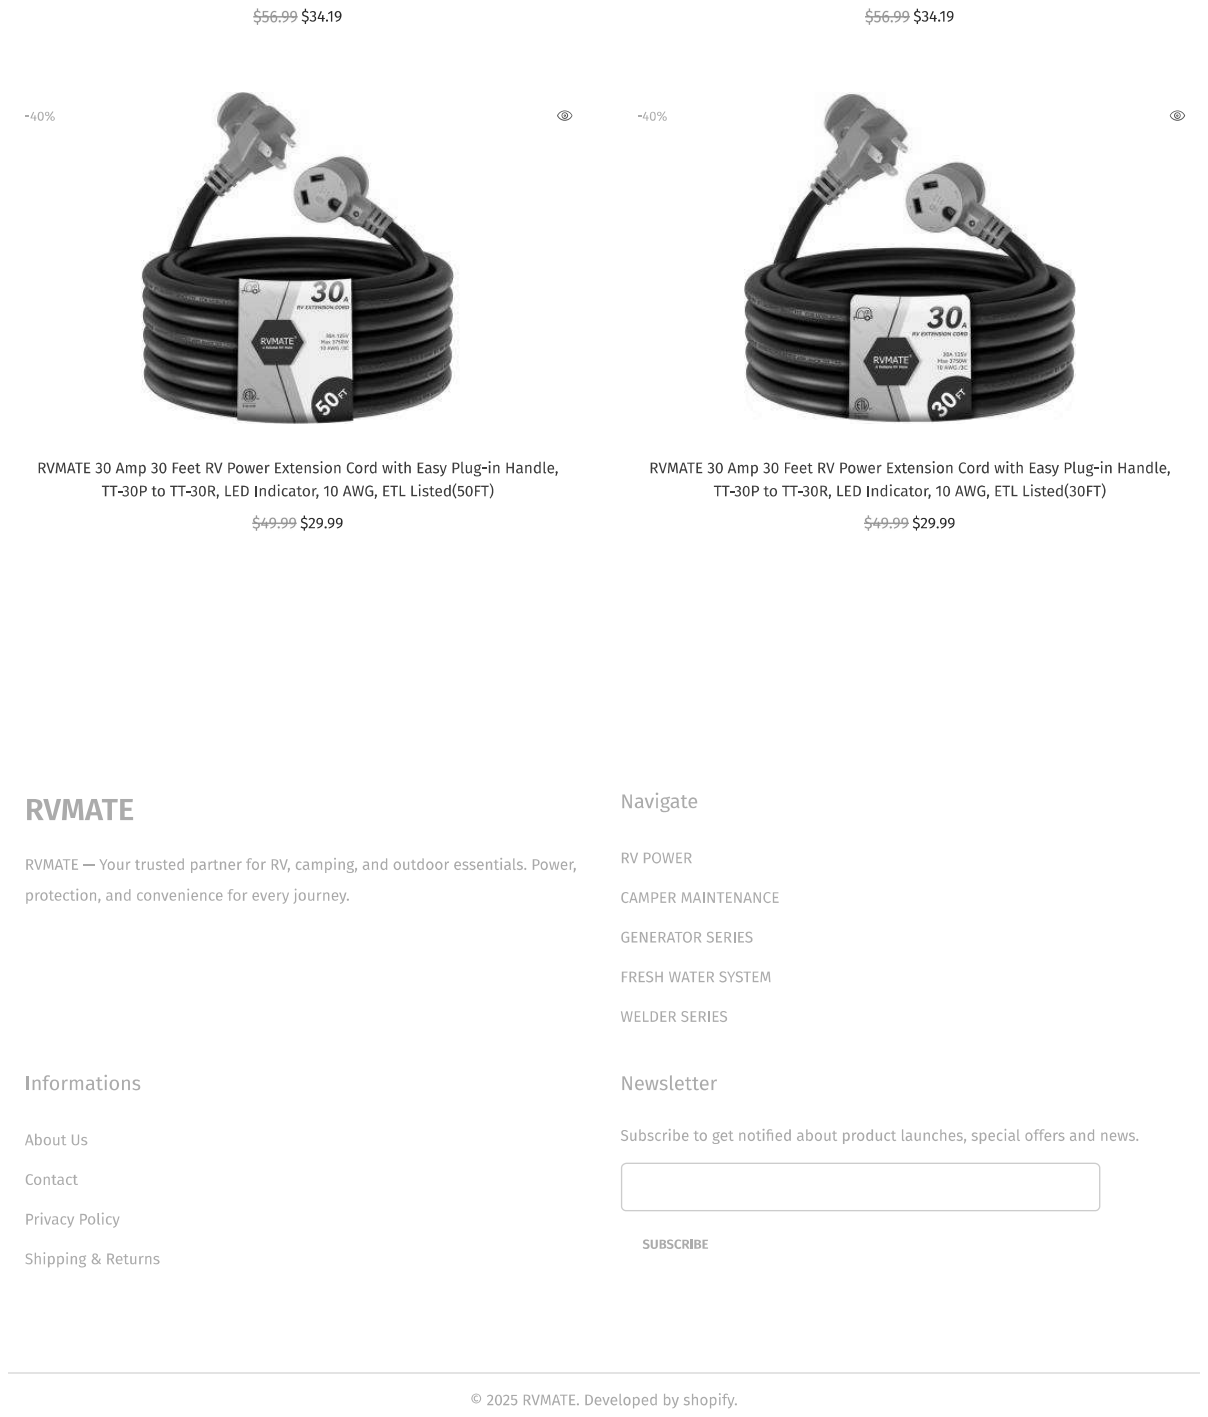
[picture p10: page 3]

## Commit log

2026-04-14 Generate first-pass Slate 2026 RV electrical schematic
    Adds DXF, SVG, and notes deliverables built from source-diagram.pdf and
    system-spec.md. Includes a Python generator that lays out four bands
    (charging, main DC, DC distribution with loads, AC) using only
    orthogonal lines, rectangles, and text on ELEC-DC / ELEC-AC / ELEC-GND /
    TEXT layers.
    https://claude.ai/code/session_018ayHN5nz1dWDqYpjFvxCDb
    [slate_electrical_schematic.dxf]
2026-04-14 Revise prompt for RV electrical schematic generation
    Updated the prompt for generating an RV electrical schematic to include additional requirements and clarify the use of BOM details and drawing content.
2026-04-14 Re-label top-band breakers and add Chassis Battery feed
    - 25A Breaker -> '25A Solar Input Protection'
    - 60A Surface Mount Breaker -> '60A Main Charge Protection'
    - 80A Breaker -> '80A Alternator Protection'
    - Add Chassis Battery component in the top band
    - Route 4 AWG conductor from Chassis Battery to the 80A breaker
    - Reroute 80A -> DC-DC + MPPT conductor over the top band to avoid
    passing through the DCDC rectangle
    - Update notes to document the new breaker roles
    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
    [slate_electrical_schematic.dxf]
2026-04-14 Add 125°C wire rating and DC demand load calculation
    - Append 125°C insulation rating to every AWG/cable-size label via
    the w() helper (applies across all DC and AC conductor callouts)
    - Verify alternator and battery paths remain strictly 4 AWG:
    Chassis Battery -> 80A Alternator Protection (4 AWG 125°C)
    80A Alternator Protection -> DC-DC + MPPT (4 AWG 125°C)
    DC-DC + MPPT -> 60A Main Charge Protection (4 AWG 125°C)
    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
    [slate_electrical_schematic.dxf]
2026-04-14 Phase 1 Charging System Lock
    Replace generator with Phase 1 baseline:
    - Scope reduced to the charging subsystem (Solar, 25A Solar Breaker,
    DC-DC + MPPT, 60A Charge Breaker, 80A Alt Breaker, Chassis Battery,
    House Battery) plus the alternator side-tap
    - DXF STYLE table now assigns Arial to STANDARD (replaces txt SHX font)
    - Wire temperature rating uses AutoCAD's \\U+00B0 Unicode escape for
    the degree glyph so it renders correctly in any DXF viewer
    Middle band, DC distribution, DC loads, AC band, and grounds from the
    prior full schematic are intentionally dropped in this phase and will
    be rebuilt on top of this foundation in later phases.
    https://claude.ai/code/session_018ayHN5nz1dWDqY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
    [slate_electrical_schematic.dxf]
2026-04-14 Restore SVG writer and archive Phase 0 outputs
    - generate_schematic.py: add write_svg() kept in lockstep with write_dxf(),
    converting the AutoCAD \\U+00B0 degree escape to a literal ° for the
    SVG. Font-family is 'Arial, Helvetica, sans-serif' to match the DXF
    STANDARD style.
    - Move Phase 0 artifacts under output/phase0_archive/ for reference
    while later phases are layered onto the Phase 1 foundation:
    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
2026-04-14 Document phased delivery plan in system-spec.md
    Add a 'Delivery phases' section immediately after the Goal section so the
    intentional phased scope is obvious to any reviewer (automated or human).
    The 'Required system content' list below now explicitly represents the
    end-state scope across all phases combined, not the scope of any single
    intermediate phase.
    Phase table:
    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
2026-04-14 Remove vendor/technical reference PDFs from repo root
    Hard-delete 17 vendor spec PDFs and 1 PNG that were sitting at the
    repository root, cluttering the main branch. Files removed:
    ALPHA_2_PRO-Specification-20240812v3.pdf
    AirPlus_ Smoke – NomadicArk.pdf
    Airplus-CSA-COFC_80265371_EN.pdf
    Bussman Series 18X Hi-Amp Circuit Breaker.pdf
    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
2026-04-14 Add GitHub Actions workflow for file organization and build
    This workflow automates the organization of tech files and builds a schematic using Python scripts. It includes steps for checking out code, setting up Python, running organization logic, generating 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
2026-04-14 Standardized folder structure and generated schematic
    [slate_electrical_schematic.dxf]
2026-04-14 Fix schematic generator and workflow
    - Delete generate_schematic_v2.py (unused placeholder)
    - Delete .github/workflows/main.yml (stale duplicate; organize-and-build.yml is the canonical workflow with bot-loop guard)
    https://claude.ai/code/session_015u3WuU2pJd3Z14UudRYL14
2026-04-14 Add CLAUDE.md operating policy
    Documents the full operating framework for AI-assisted work in this repo:
    purpose, conflict policy, versioning/archival rules, drawing standards,
    automation rules, and scope limits.
    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
2026-04-14 Fix pipeline: unblock output commits and harden organizer
    Root cause: output/ was in .gitignore so git add . never staged
    generated DXF/SVG — every workflow run ended with "No changes to
    commit" and produced no persistent artifacts.
    Changes:
    - .gitignore: remove output/ entry so generated files are trackable
    - organize_repo.py:
    - add PROTECTED_FILES set (source-diagram.pdf and other root inputs
    are never moved or deleted)
    - archive_outputs() now covers DXF as well as SVG
    - archive filenames include a UTC timestamp so the archive is never
    silently overwritten on a second run
    - import datetime added
    generate_schematic.py: verified clean, no changes needed.
    Workflow: verifie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
2026-04-14 Organized repo and regenerated schematic
    [slate_electrical_schematic_20260414T053629.dxf]
2026-04-14 Fix organizer: classify PDFs from both root and technical/ root
    Root cause of files stuck in technical/:
    organize_repo.py scanned only Path(".").glob("*.pdf") — strictly the
    repo root. The 17 PDFs already sitting in technical/ root were never
    in scope. Every CI run was a complete no-op for those files.
    - Scan both repo root and technical/ root (non-recursive glob on each)
    - Classify by filename keywords into certs / datasheets / manuals;
    unmatched files go to technical/engineering/archive_phase0
    - ROUTING_RULES list replaces the single-bucket "dump to manuals" logic
    - safe_move() handles destination collisions: delete exact duplicates,
    timestamp-suffix differing files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
2026-04-14 Reset organizer to safe intake-only mode
    Removed dangerous behavior before source document re-upload:
    - No duplicate deletion (unlink() removed entirely)
    - No technical/ scanning (scope reduced to repo root only)
    - Collision policy changed: if destination exists, leave source
    in place and print a conflict message — nothing is overwritten
    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
2026-04-14 Refine Phase 1 charging schematic layout
    Drawing-cleanup pass only — no system logic changed.
    - DC-DC label: '(Solar + Alt Inputs)' -> '(Solar + Alt)' (less crowded)
    - BAT position: x 730 -> 1050, aligning center (1160) directly under
    B60A center (1160); eliminates the horizontal jog in the drop wire
    - B60A -> BAT wire: 4-point jog replaced with straight 2-point vertical
    (1160, 280) -> (1160, 540) in SVG coords — single clean segment
    - Alternator overhead routing: y 1850 -> 1890 in DXF (SVG y 150 -> 110),
    giving 70px clearance above component tops instead of 30px
    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
    [slate_electrical_schematic.dxf]
2026-04-14 Final schematic layout cleanup pass
    - Alternator overhead routing: raised from DXF y=1890 to y=1920
    (SVG y=110 -> y=80), giving 100px clearance above component tops
    - Wire labels: offset increased to 15 units in both DXF and SVG,
    consistent for horizontal (above) and vertical (right) wires
    - DC-DC label, BAT centering under B60A, straight B60A->BAT
    vertical drop all verified correct from prior pass
    No components added. No wire topology changed.
    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
    [slate_electrical_schematic.dxf]
2026-04-14 Add Phase 2 distribution components to electrical schematic
    Adds 200A main breaker, 300A shunt, positive bus, negative bus, and
    chassis ground below the house battery. All five new wire segments are
    pure vertical drops — no diagonal routing. Phase 1 layout unchanged.
    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
    [slate_electrical_schematic.dxf]
2026-04-14 Phase 2 schematic correction pass
    - Reroute DC-DC positive: B60A now feeds POSITIVE BUS (not battery directly)
    - Add DC-DC negative return to NEGATIVE BUS via x=640 column (clear of BAT)
    - Center bus bars within battery footprint: each bus w=100, pair spans 730-950
    - Align B200A/SHUNT centers to bus centers using interior BAT tap points
    - All Phase 2 distribution wires remain vertical; 2/0 AWG labels intact
    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
    [slate_electrical_schematic.dxf]
2026-04-14 Add Phase 3: AC system, inverter, and DC/AC distribution panels
    - SHORE INLET (30A): lower-left, AC layer
    - INVERTER / CHARGER / TRANSFER SWITCH (UL458): feeds from POSBUS/NEGBUS
    DC+/DC- routed clear of CHASGRND and each other (separate y-channels)
    - AC DISTRIBUTION PANEL with GFCI 1 (15A), GFCI 2 (15A), OPTIONAL AC (20A) stubs
    - DC DISTRIBUTION PANEL: 12 branch circuits F1–F12 listed in box
    Fed from POSBUS right; NEGBUS enters at separate height as neg ref
    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
    [slate_electrical_schematic.dxf]
